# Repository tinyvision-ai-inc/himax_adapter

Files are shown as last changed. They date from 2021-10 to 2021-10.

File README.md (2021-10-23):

# UPduino Himax Adapter

The UPduino Himax adapter is sold by Lattice Semiconductor and manufactured by tinyVision.ai Inc.

The design was done in the Altium tool and is open sourced with permission from Lattice Semiconductor.

## Design Notes
This design improves significantly on the original design of the Himax shield in the following ways:
1. 4 Layer board with proper ground/power planes and good layout
2. Voltage translation for the Himax sensor. The original design ran the sensor I/O at 3.3V which is outside the specified range, potentially causing long term degradation to the part.
3. Added IR LED drivers. The camera sensor can be replaced with a sensor that has no IR cut filter and the IR LED's can be used to illuminate the scene for gesture detection as well as other applications.
4. Improved microphone location: The 2 microphones in the original design were placed very close to each other resulting in no real gain from 2 mics. By spacing these as far apart as possible, we can use these for interesting applications such as beam forming for noise reduction, direction of arrival etc.

## Support
tinyVision.ai can provide support for this board on a best effort basis only. Please reach out to your local Lattice FAE as well. We are available to consult if you would like to incorporate the design into your application.

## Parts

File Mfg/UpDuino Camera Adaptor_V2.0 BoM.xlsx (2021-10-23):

Comment | Description | Designator | Footprint | LibRef | Quantity | MPN
0.1uF | CAP CER 0.1UF 6.3V X5R 0603 | C1, C2, C6, C7, C8, C10, C11, C12, C13, C14, C16, C18, C20, C22, C23, C24 | C0603 | Cap_100nF_X7R_10%_0603 | 16 | CC0603KRX7R0BB104
4.7uF | CAP CER 4.7UF 6.3V X5R 0603 | C4, C9, C19, C21, C25, C26 | C0603 | Cap_100nF_X7R_10%_0603 | 6 | LMK107BJ475MAHT
1nF | CAP CER 0.1UF 6.3V X5R 0603 | C5 | C0603 | Cap_100nF_X7R_10%_0603 | 1 | CC0603KRX7R0BB102
220pF | CAP CER 220pF 6.3V X5R 0603 | C15, C17 | C0603 | CAP | 2 | CC0603KRX7R9BB221
VSMY3850 | EMITTER IR 850NM 70MA 3.20MM SMD | D1, D2 | PLCC-2 | LED | 2 | VSMY3850-GS18
GREEN | Liteon LTST-C191KGKT | DS1, DS2, DS3, DS4, DS5, DS6 | LED_0603_12 | LED_1 | 6 | LTST-C191KGKT
503772-2420 | Header, 12-Pin, Dual row | J2 | MOLEX-5037722410_MOLEX | Header 12X2A | 1 | 503772-2420
SPH0645LM4H-B | Mic Mems Digital I2s Omni -26db | MK1, MK2 | *MIC_SPH0645LM4H-B | SPH0645LM4H-B | 2 | SPH0645LM4H-B
2N7002-G | MOSFET (N-Channel) | Q1 | SOT23-3 | 2N7002-G | 1 | 2N7002-G
12K |  | R1, R3, R18 | R0603 | R_SH | 3 | RC0603FR-0712KL
5.6R |  | R2 | R0603 | R_SH | 1 | RC0603FR-075R6L
22R |  | R8, R16, R17 | R0603 | R_SH | 3 | RC0603FR-0722RL
1K |  | R9, R10, R11, R12, R13, R14 | R0603 | R_SH | 6 | RC0603FR-071KL
10K | EXB-28V104JX | RN1 | RN4(0402) | EXB28V | 1 | EXB-28V104JX
SN74AVC2T45DCTR | Integrated Circuit | U1 | MSOP-8(2.95x2.80) | SN74AVC2T45DCTR | 1 | SN74AVC2T45DCTR
SN74AVC16T245DGG | Integrated Circuit | U2 | TSSOP-48 | SN74AVC16T245DGG | 1 | SN74AVC16T245DGG
AL5801W6-7 | Integrated Circuit | U3 | SOT-23-6-(SSOT-6) | AL5801W6-7 | 1 | AL5801W6-7
TCR2LE28,LM(CT |  | U4 | SOT-553 | TCR2LE12ESV | 1 | TCR2LE28,LM(CT
TCR2LE18,LM(CT |  | U5 | SOT-553 | TCR2LE12ESV | 1 | TCR2LE18,LM(CT
TCR2LE15,LM(CT |  | U6 | SOT-553 | TCR2LE12ESV | 1 | TCR2LE15,LM(CT
TC7WPB9307FK,LF | Dual bidirectional level translator | U7 | SSOP8-P-0.50A | TC7WPB9307FK | 1 | TC7WPB9307FK,LF

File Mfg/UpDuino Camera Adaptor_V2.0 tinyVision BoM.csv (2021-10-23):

Qty | Part/BOM Name | Description | Designators | Comments
1 | TV-2N7002-G (2N7002-G) | MOSFET, N-CHANNEL ENHANCEMENT MODE, 60V, 7.5 Ohm 3 SOT-23 1.3mm T/R | Q1
1 | TV-503772-2420 (503772-2420) | Conn Stacking RCP 0.8mm Stack Height 24 POS 0.4mm Solder ST SMD Emboss T/R | J2
2 | TV-61001611921 (61001611921) | SMT Vertical Socket Header WR-PHD, Pitch 2.54 mm, Single Row, 16 pins | UP1,UP2
1 | TV-61300211821 (61300211821) | Female header Temperature range: -40 ... +125 °C Colour: Black Connector Design: Single Row / Straig… | J1
1 | TV-AL5801W6-7 (AL5801W6-7) | AL5801 Series 100 V Adjustable Current Sink Linear LED Driver - SOT-26 | U3
1 | TV-CAP-0603-0.1UF | 0.1uF 0603 Capacitor | C3
1 | TV-CAP-0603-1NF | 1nF 0603 capacitor | C5
2 | TV-CAP-0603-220PF | 220pF 0603 Capacitor | C15,C17
6 | TV-CAP-0603-4.7UF | 4.7uF 0603 Capacitor | C4,C9,C19,C21,C25,C26
6 | TV-LED-0603-GREEN | Green 0603 LED | DS1-DS6
4 | TV-RES-0603-0 | 0 ohm 0603 Resistor | R4-R7
3 | TV-RES-0603-12K0 | 12K 0603 Resistor | R1,R3,R18
6 | TV-RES-0603-1K0 | 1K ohm 0603 Resistor | R9-R14
3 | TV-RES-0603-22R | 22 Ohm 0603 Resistor | R8,R16,R17
1 | TV-RES-0603-5R6 | 5.6 Ohm 0603 resistor | R2
1 | TV-SN74AVC16T245DGGR (SN74AVC16T245DGGR) | 16-Bit Dual-Supply Bus Transceiver with Configurable Voltage-Level Shifting and 3-State Outputs 48-T… | U2
1 | TV-SN74AVC2T45DCTRE4 (SN74AVC2T45DCTRE4) | Ic,Bus Transceiver,Single,2-Bit,Avc/Alvc/Vcx-Cmos,Ssop,8Pin,Plastic | U1
2 | TV-SPH0645LM4H-B (SPH0645LM4H-B) | Mic Mems Digital I2s Omni -26db | MK1,MK2
1 | TV-TC7WPB9307FK,LF(CT (TC7WPB9307FK,LF(CT) | Voltage Level Translator 2-CH Unidirectional 8-Pin SSOP T/R | U7
1 | TV-TCR2LE15,LM(CT | 1.5V LDO SOT-553 | U6
1 | TV-TCR2LE18,LM(CT | 1.8V LDO | U5
1 | TV-TCR2LE28,LM(CT | 2.8V LDO SOT-553 | U4
2 | TV-VSMY3850-GS18 (VSMY3850-GS18) | LED IrLED 850nm 2-Pin PLCC T/R | D1,D2

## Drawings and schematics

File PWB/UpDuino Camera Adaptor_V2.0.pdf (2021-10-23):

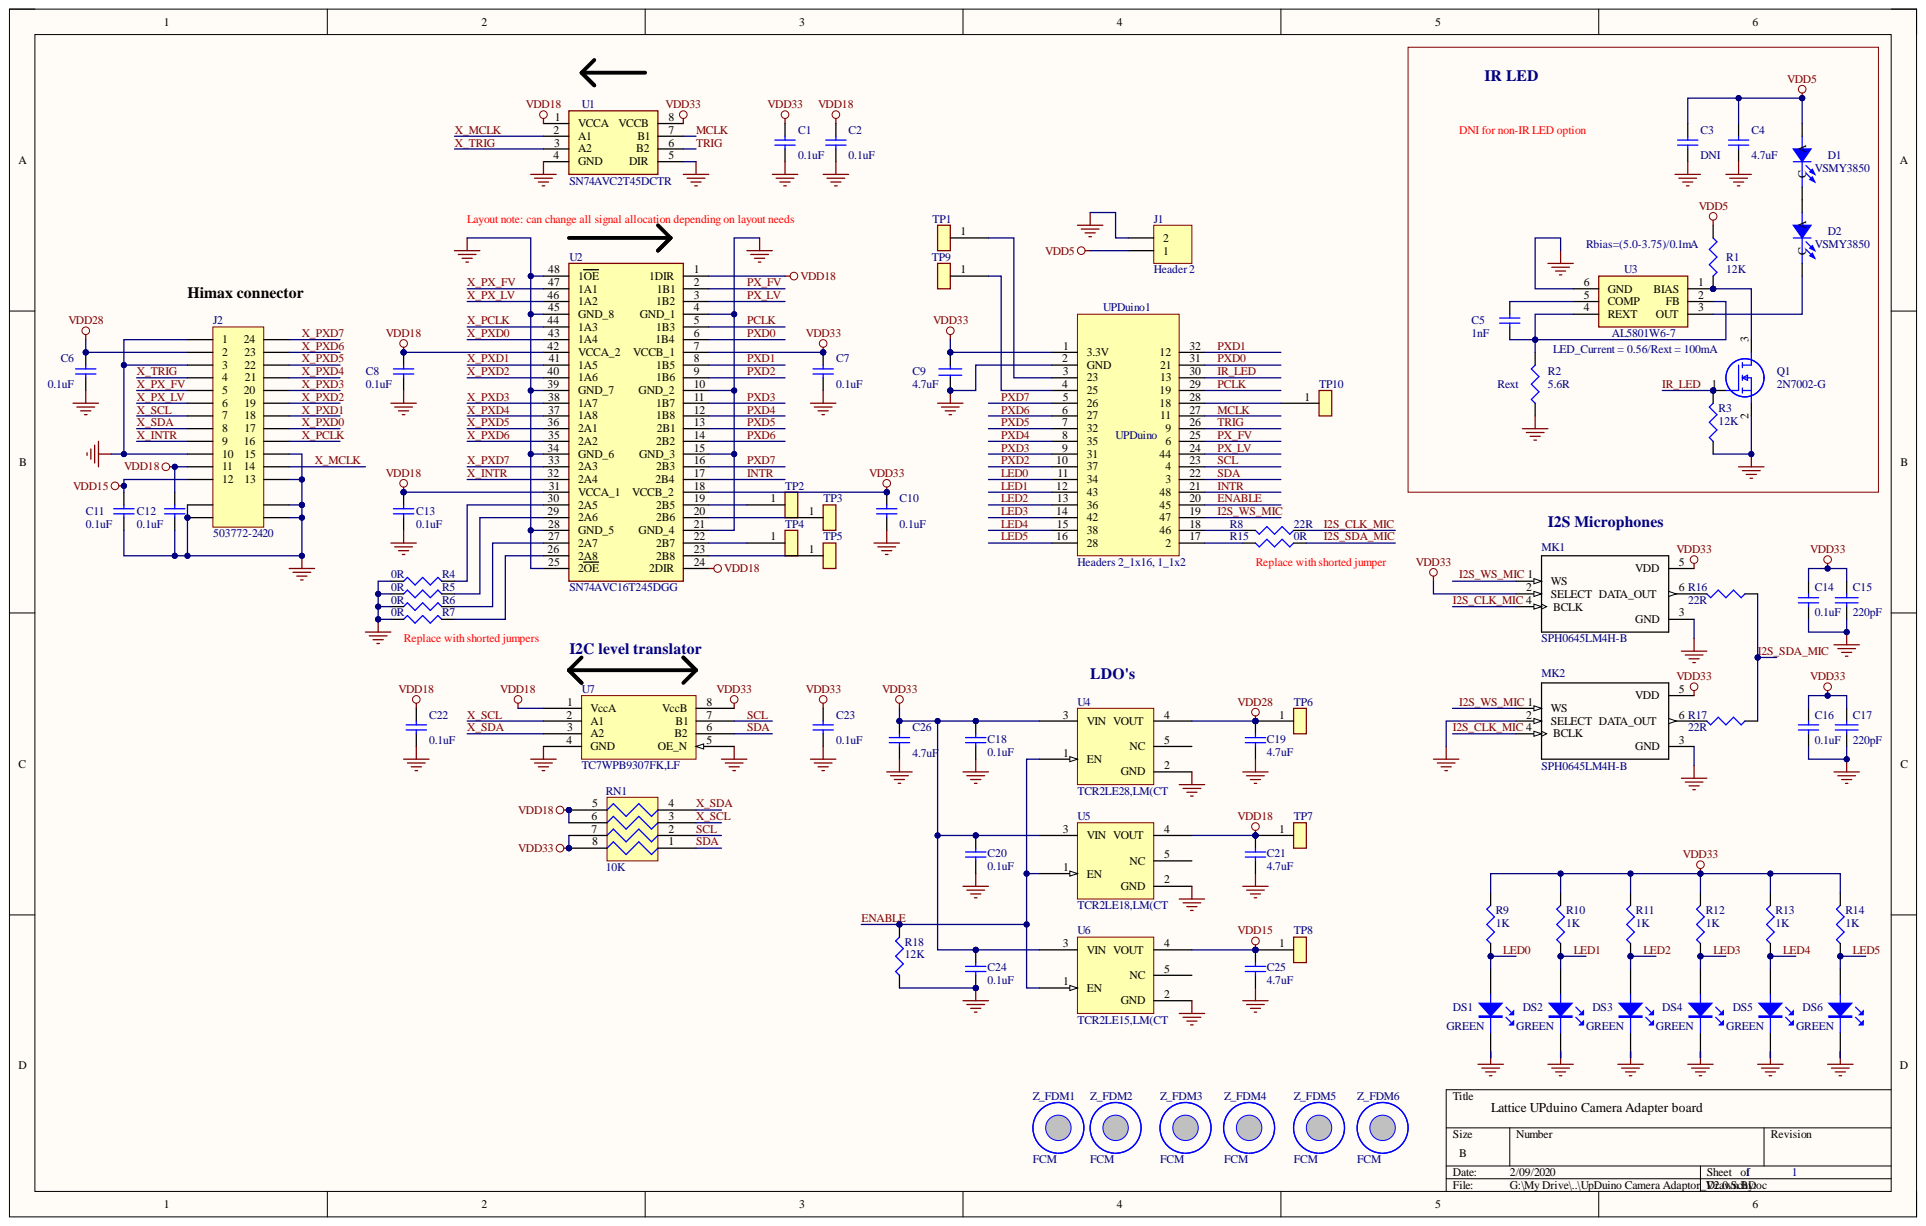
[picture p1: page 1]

DNI for non-IR LED option

Layout note: can change all signal allocation depending on layout needs

2A8 26
2OE 25

Replace with shorted jumper

Replace with shorted jumpers

Lattice UPduino Camera Adapter board Z_FDM1

Size B | Number | Revision

Date: 2/09/2020 | Sheet of 1 1
File: G:\My Drive\..\UpDuino Camera Adaptor_VD2.0.Sch rawnBDy:oc
